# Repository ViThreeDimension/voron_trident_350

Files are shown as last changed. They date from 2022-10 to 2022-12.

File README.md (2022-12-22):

# My Voron Trident 350

This documentation is to know where to find replacement parts for the mods. 
When I will be at the software step, I will add klipper configs, make files. 

Built from this [Voron Trident R1 commit](https://github.com/VoronDesign/Voron-Trident/tree/VTr1)

[Voron 2.4 R0 - 300](https://github.com/ViThreeDimension/voron2.4) big brother

## Mods
- [Carbon Pin Mod](/mods/own%20mods/Trident%20Carbon%20Pin%20Mod/) (slightly lower holes diameter) based on [hartk pin mod](https://github.com/VoronDesign/VoronUsers/tree/master/printer_mods/hartk1213/Voron2.4_Trident_Pins_Mod) - [(fork)](https://github.com/ViThreeDimension/VoronUsers/tree/timelocked-mods/Trident/printer_mods/hartk1213/Voron2.4_Trident_Pins_Mod)
- [Fish3DP's front idlers "Tackle Box"](/mods/fishTackleBox/Fish%20Tackle%20Box%20other_front_idler.md)
- Umbelical
- Can Toolhead SHT-36
  - [Can Mount](/mods/STH-36_sherpa_mini_mounting_plate_overmold_strain.stl) from [KayorMaker Can Mount Repo](https://github.com/KayosMaker/CANboard_Mounts)
  - [CanBus Documentation](documentation_subpages/CAN%20configuration.md)
- [Toolhead smol mantis](/mods/smol_mantis/) from [FoonieTunes repo](https://github.com/sporkus/smol_mantis)
  - [Sherpa mini from annex](https://github.com/Annex-Engineering/Sherpa_Mini-Extruder)
  - [Mini Sherpa Angled Front Brace from Mandryd](https://github.com/Annex-Engineering/Annex-Engineering_User_Mods/tree/main/Extruders/Sherpa_Mini/Extruder_Mods/Long-housing_front_angled_front_brace)
  - Can Bus SHT-36 - [Documentation](https://mellow.klipper.cn/#/board/fly_sht36_42/)
- [KlickyNG](https://github.com/ViThreeDimension/Klicky-Probe/tree/timelocked-mods/Trident)
- [Sexbolt for Trident with kinematic bed](/mods/sexbolt%20trident%20for%20kinematic%20bed/) based on [sexbolt by hartk](https://github.com/hartk1213/MISC/tree/main/Voron%20Mods/Voron%202/2.4/Voron2.4_SexBolt_ZEndstop)
- Panel locker [by V6C1](https://github.com/v6cl/My-Voron2.4-Customs/tree/main/Panel_Locker)
- V2.2 doors modified for 5mm acrylic and 8mm foam: [here](mods/front%20panel%20handle)
- Gantry Backers [by whoppingpochard](https://github.com/ViThreeDimension/VoronUsers/tree/timelocked-mods/Trident/printer_mods/whoppingpochard/extrusion_backers)
- Trident kinematic_bed [by whoppingpochard](https://github.com/tanaes/whopping_Voron_mods/tree/main/kinematic_bed)
- [Nevermore](https://github.com/nevermore3d/Nevermore_Micro) and Nevermore Extension [by Outrider305](https://github.com/Outrider305/Nevermore_Spacer_Mount) - ([cache](https://github.com/ViThreeDimension/Nevermore_Spacer_Mount))
- [Decontaminator Bucket and brush](https://github.com/LoganFraser/VoronMods/blob/main/DecontaminatorTrident/)
- 
## Electronics
- 24v alimentation & 48v for A-B Motors
- SHT36 v1 for Toolhead - [Documentation](https://mellow.klipper.cn/#/board/fly_sht36_42/)
- Octopus Pro 446 main board 
  - [Official Documentation](https://github.com/bigtreetech/BIGTREETECH-OCTOPUS-Pro/) - [(cached)](documentation_subpages/BTT_Octopus_pro_EN.pdf)
  - [Klipper Installation (VoronDocs)](https://docs.vorondesign.com/build/software/octopus_klipper.html)
  - [My doc](documentation_subpages/BTT_Octopus_pro_vince.md)
- 110V bed heater

# Todo
- ADXL: Add Front keystone skirt

# Wishlist to sort
- [gcode buttons](https://github.com/VoronDesign/VoronUsers/tree/master/legacy_printers/printer_mods/meteyou/gcode_buttons)

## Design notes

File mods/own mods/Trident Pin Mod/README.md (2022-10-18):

Pin mod for the Voron Trident based on Hartk V2 work.

Need to print all gantry parts that has Idlers
- AB drive frames
- XY Joints
- Front Tensioners

Files

BOM
[A-B] 
threaded(or not) @  30mm (x2)
smooth   @  28mm (x2)

[X-Y Joints]
smooth   @  40mm (x4)

[X-Y Idlers]
smooth   @  43mm (x2)

Smooth pins

https://www.aliexpress.com/item/1739093502.html

threaded pins

https://www.ebay.com/itm/%CF%865mm-%CF%8612mm-Female-Thread-Cylindrical-Pin-Dowel-Pins-A2-304-Stainless-Steel/184373551069

Misumi Part Numbers
Part NO. 	Qty
SFRT5-30-M3 	2
SFR5-43 	2
SFR5-40 	4
SFR5-28 	2

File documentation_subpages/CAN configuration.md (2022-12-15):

# CAN Documentation

- [TeamFDM - how to use can toolhead boards connected directly to octopus pro](https://www.teamfdm.com/forums/topic/672-how-to-use-can-toolhead-boards-connected-directly-to-octopus-octopus-pro-on-canboot/)
- [Octopus Pro Documentation](https://github.com/bigtreetech/BIGTREETECH-OCTOPUS-Pro/) - [(cached pdf)](BTT_Octopus_pro_EN.pdf)
- [Mellow SHT36 CanBus Toolhead](https://mellow.klipper.cn/#/advanced/canboot)
  - UTOC device -> Bus 001 Device 003: ID 1d50:606f OpenMoko, Inc. 
- [Octopus and SB2040](https://github.com/akhamar/voron_canbus_octopus_sb2040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)
- [Maz0r Canbus for Klipper](https://maz0r.github.io/klipper_canbus/)
- EddieTheEngineer Videos
  - [Klipper Mainsail Can setup guide](https://www.youtube.com/watch?v=XkcxSQhRR3I)
  - [BTT EBB V1.0 CAN Setup Guide](https://www.youtube.com/watch?v=_FELCN8CbWA)
  - [Flash your Huvud over Canbus!](https://www.youtube.com/watch?v=YrF99Sff9g8)
  - [Flash all your klipper MCUs with 1 script](https://www.youtube.com/watch?v=1P4UrJxChL8) 

# My CAN configuration
- Start with UTOC-3 from Mazor https://maz0r.github.io/klipper_canbus/controller/utoc1-3.html

## PI Setup

` sudo nano /etc/network/interfaces.d/can0 `

auto can0
iface can0 can static
 bitrate 500000
 up ifconfig $IFACE txqueuelen 256
 pre-up ip link set can0 type can bitrate 500000
 pre-up ip link set can0 txqueuelen 256

and press Ctrl+X to save.

you can now reboot the pi with ` sudo reboot `
## Test the network

Once the pi has rebooted you can run the ip -s link show can0 command to check your network status.

You should see a line like the below in the results. The key thing to note is that the network is UP for now.

iplink

- If not working test this 
https://mellow.klipper.cn/#/advanced/can_rpi

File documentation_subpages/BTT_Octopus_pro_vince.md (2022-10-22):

# Settings Up Octopus Pro via USB-Powered (from PI) and DFU Mode  
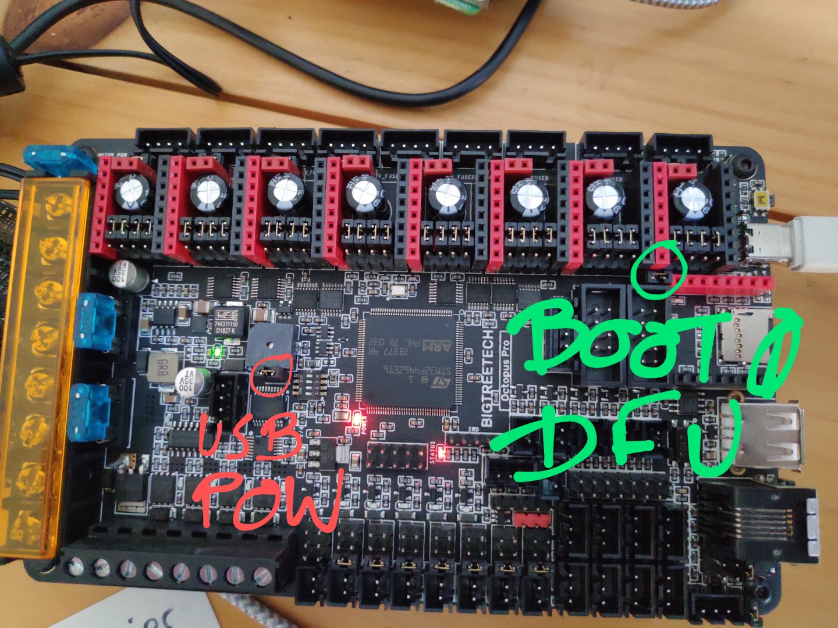
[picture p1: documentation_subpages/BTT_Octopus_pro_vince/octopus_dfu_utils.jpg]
Octopus pro in DFU-Utils/Boot0 mode


# Restore factory Octopus STM32F446 bootloader 
> Documentation by Dragonkitty ▞ replimat.eu - Drachenkätzchen#3832

My Octopus F446 wouldn't boot the Klipper CAN Firmware, so I hunted this down to a incompatible bootloader installed by BTT.
Surprisingly, their published bootloader on Github works. Here's how to flash it using dfu-util after putting the
board into DFU boot mode:

```
# Downloads the firmware file in Intel HEX format
wget https://raw.githubusercontent.com/bigtreetech/BIGTREETECH-OCTOPUS-V1.0/master/Firmware/DFU%20Update%20bootloader/bootloader/OctoPus-F446-bootloader-32KB.hex

# Converts the hex firmware to a bin
objcopy --input-target=ihex --output-target=binary OctoPus-F446-bootloader-32KB.hex bootloader.bin

# Optional: Backup the old bootloader
sudo dfu-util -d ,0483:df11 -R -a 0 -s 0x8000000:32768 -U old-bootloader.bin

# Install the new bootloader
sudo dfu-util -d ,0483:df11 -R -a 0 -s 0x8000000:leave -D bootloader.bin
```

Reset bootloader per @Dragonkitty ▞ replimat.eu  pin in CAN Bus stop  if required

# Configure Octopus in USB-Bridge Can bus
> Documentation by Maz | v2.☕ - maz#1337

- Configure [like normal Octopus firmware](https://docs.vorondesign.com/build/software/octopus_klipper.html) except change two the comms port & the can pins (screenshot for F446)
```
cd ~/klipper
make menuconfig
```
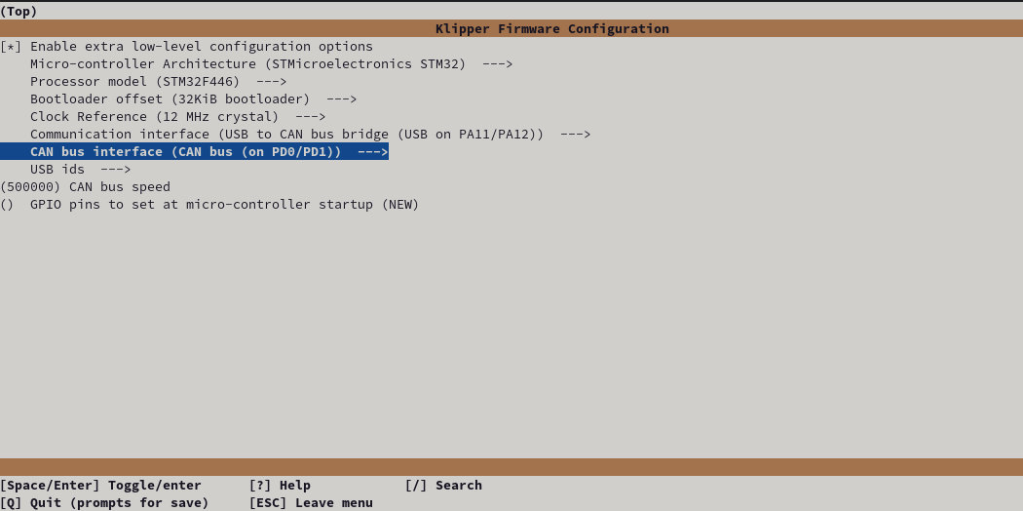
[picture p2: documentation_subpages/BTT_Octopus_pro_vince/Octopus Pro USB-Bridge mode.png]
outlined wiring


- setup CAN0 network 
```
sudo nano /etc/network/interfaces.d/can0
allow-hotplug can0
iface can0 can static
   bitrate 500000
   up ifconfig $IFACE txqueuelen 256
   pre-up ip link set can0 type can bitrate 500000
   pre-up ip link set can0 txqueueln 256
```

- continue setup of upstream devices which will be connected via a RJ11/12 breakout on the octopus

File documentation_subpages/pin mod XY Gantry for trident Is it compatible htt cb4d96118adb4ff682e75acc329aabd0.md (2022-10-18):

# pin mod XY Gantry for trident? Is it compatible? https://github.com/hartk1213/MISC/tree/main/Voron Mods/Voron 2/2.4/Voron2.4_Pins_Mod

- Need to tweak ab motors holder for this too

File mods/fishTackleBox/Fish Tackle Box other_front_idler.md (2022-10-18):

# Fish3DP (discord Fish3DP#2205) Tackle Box front idlers

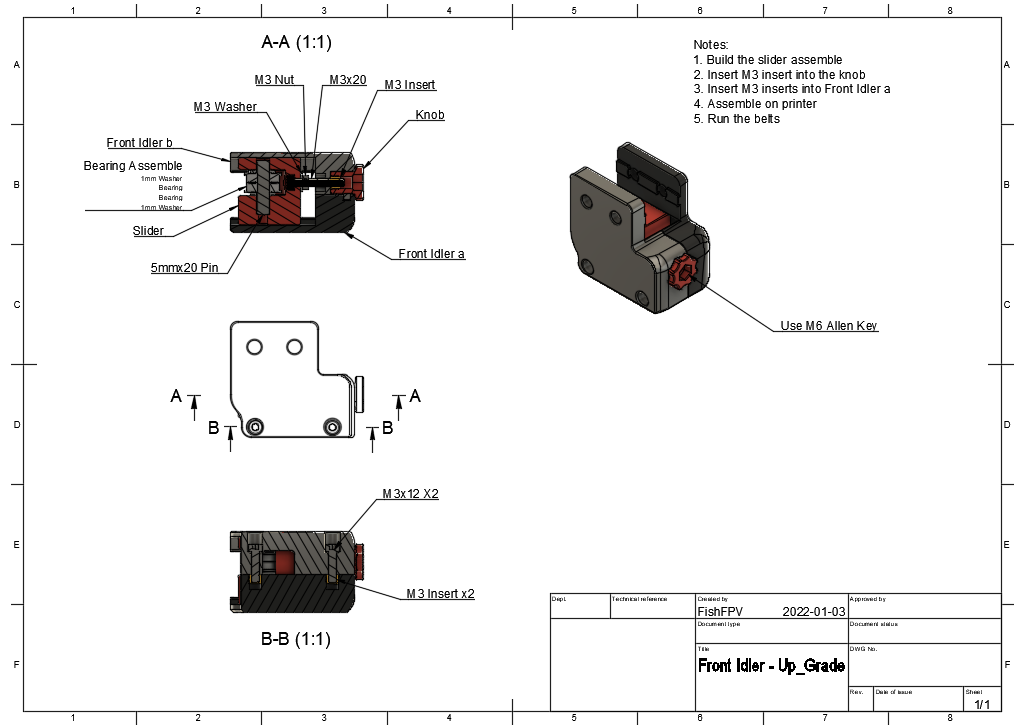
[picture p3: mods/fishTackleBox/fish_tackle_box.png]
fish tackle box.png


[Fishs_Tackle_Box_Tensions.zip](Fishs_Tackle_Box_Tensions.zip)

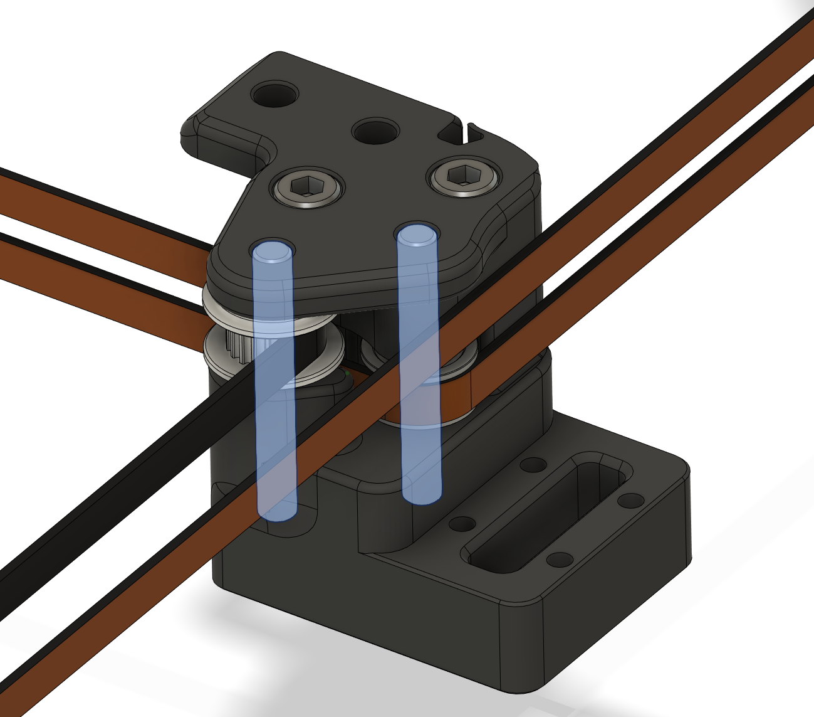
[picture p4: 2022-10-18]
mods/own mods/Trident Pin Mod/Images/XY_Right_Joint.png

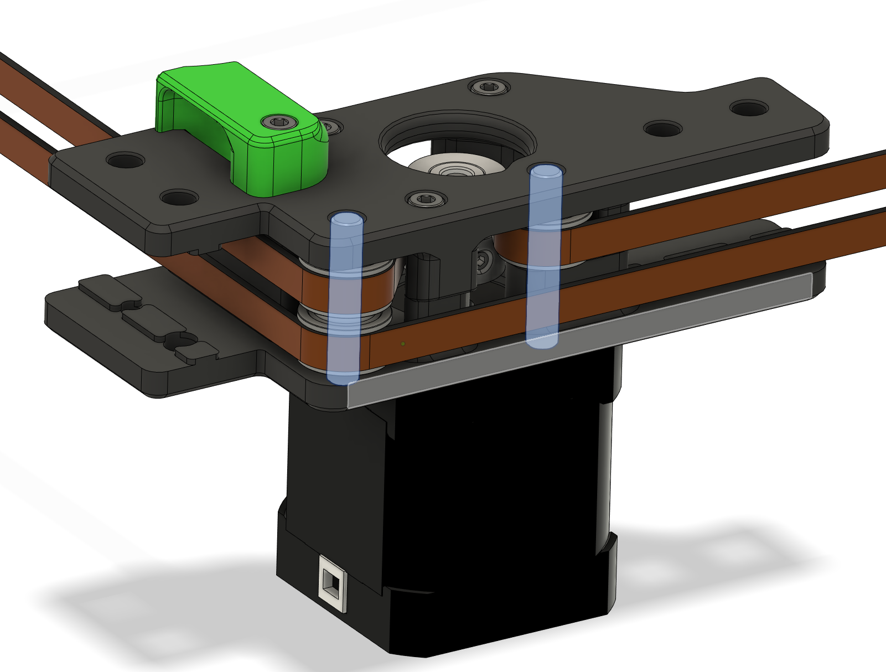
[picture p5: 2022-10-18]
mods/own mods/Trident Pin Mod/Images/A_Motor_Plate.png

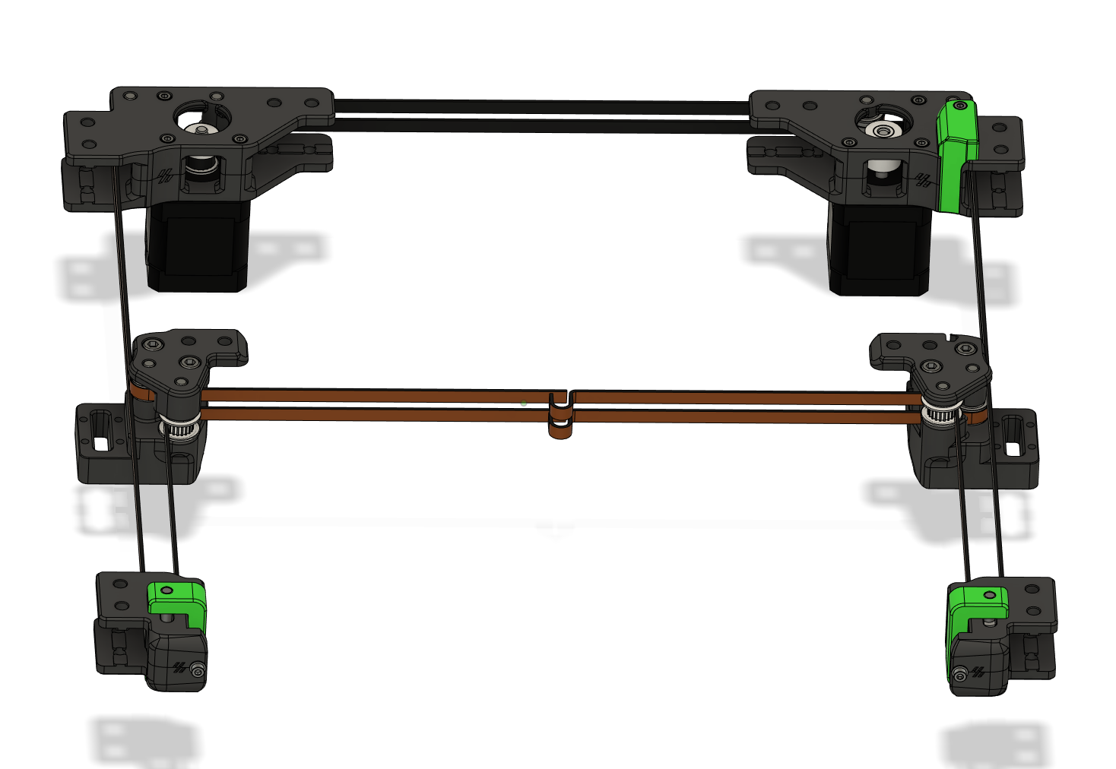
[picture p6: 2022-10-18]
mods/own mods/Trident Pin Mod/Images/Gantry.png

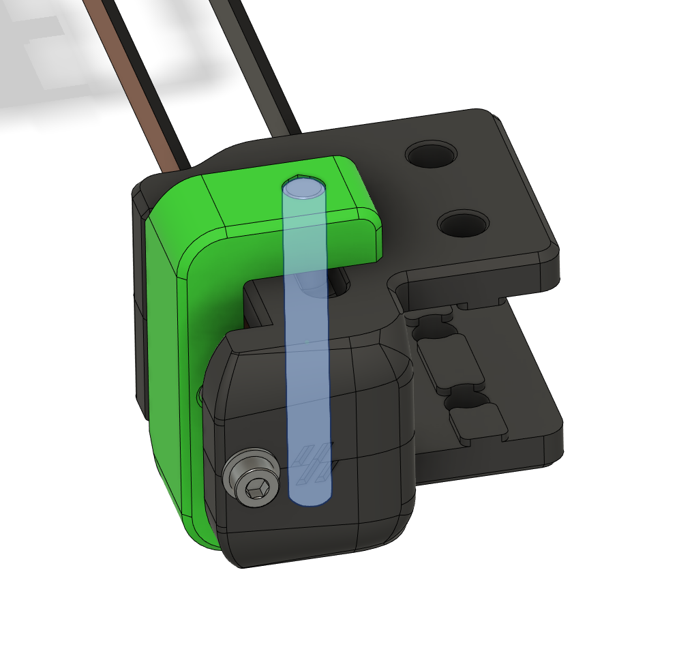
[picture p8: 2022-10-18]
mods/own mods/Trident Pin Mod/Images/Right_Idler.png

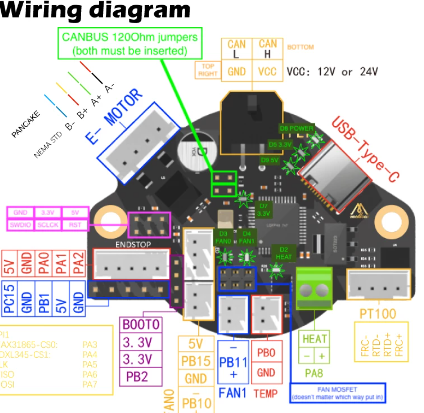
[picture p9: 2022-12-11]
documentation_subpages/sht36diag.png

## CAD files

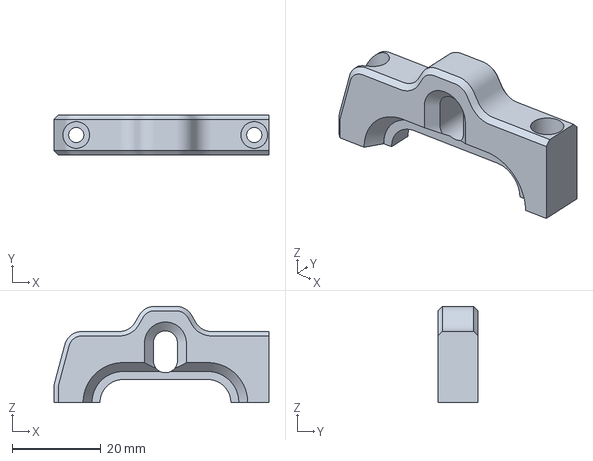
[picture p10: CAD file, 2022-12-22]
mods/front panel handle/handle_sandwich.3mf
48.3 x 9.00 x 21.6 mm

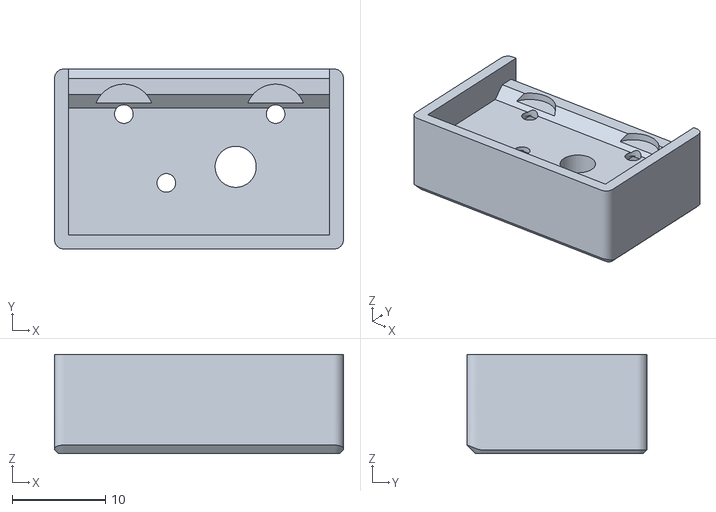
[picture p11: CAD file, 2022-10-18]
mods/klickyNG/KlickyNG_cap_magnet helper.stl
30.9 x 19.3 x 10.6

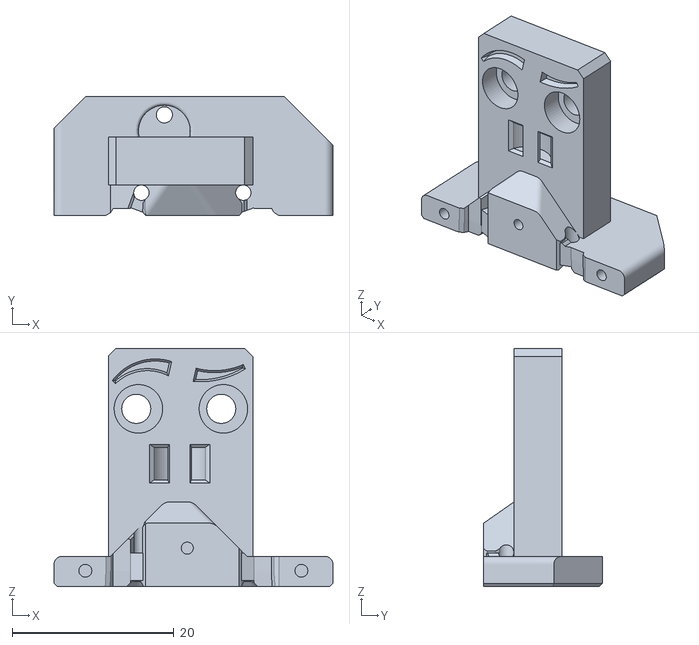
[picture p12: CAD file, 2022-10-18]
mods/klickyNG/STL/KlickyNG_ABSB_mount_base.stl
34.5 x 14.7 x 29.4

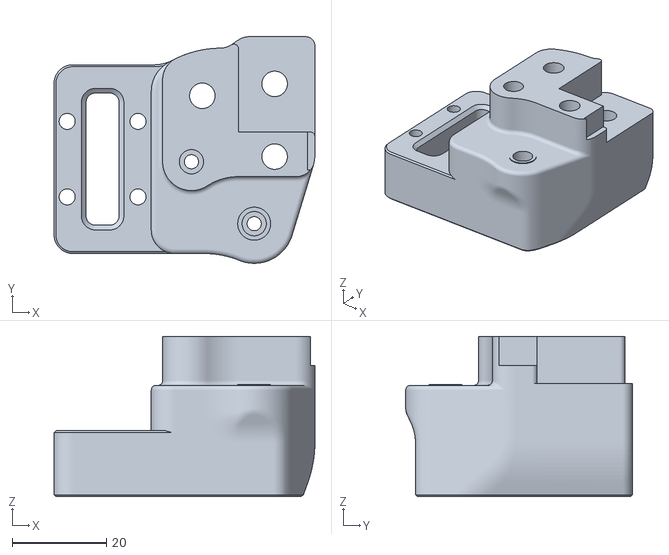
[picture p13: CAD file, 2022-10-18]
mods/own mods/Trident Carbon Pin Mod/xy_joint_left_lower_MGN12_pinned.stl
55.3 x 48.0 x 34.0

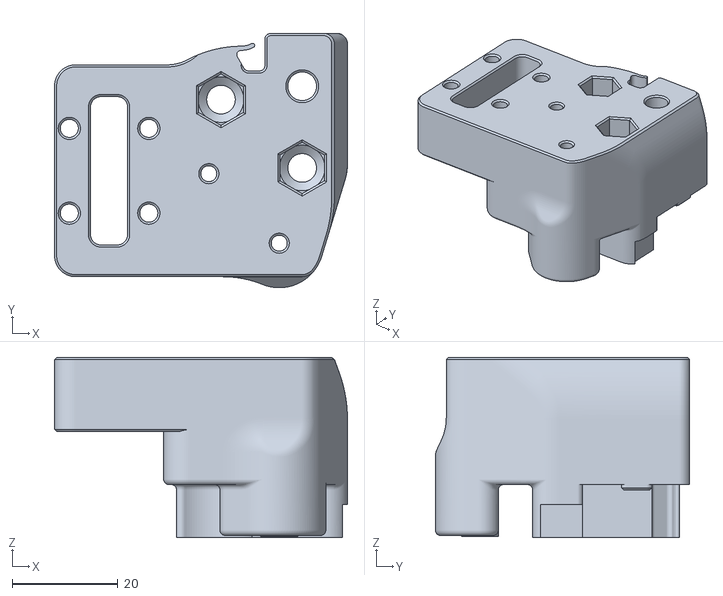
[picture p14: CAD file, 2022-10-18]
mods/own mods/Trident Pin Mod/STLs/xy_joint_right_lower_MGN12_pinned.stl
55.3 x 48.0 x 34.0

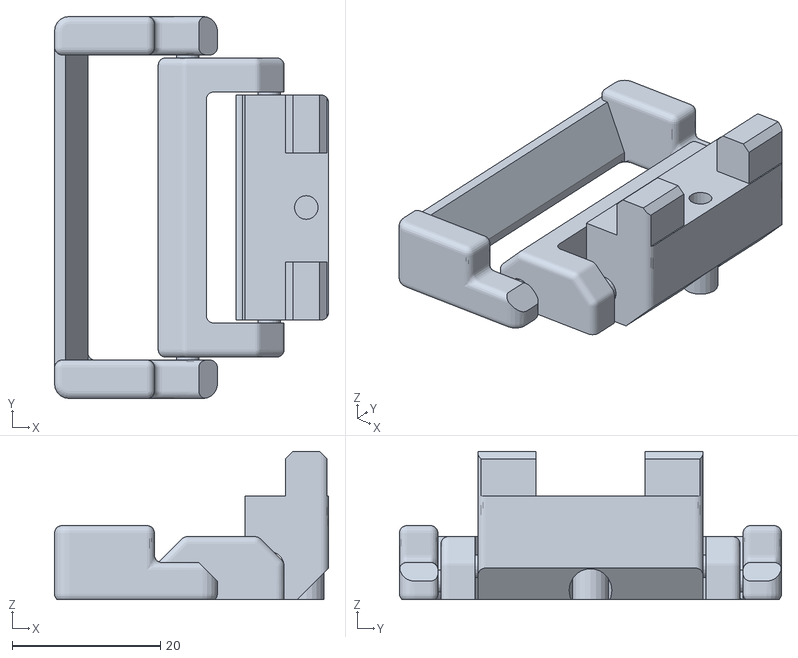
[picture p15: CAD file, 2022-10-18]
mods/Panel_Locker/Locker_5mm.stl
37.0 x 51.6 x 20.0

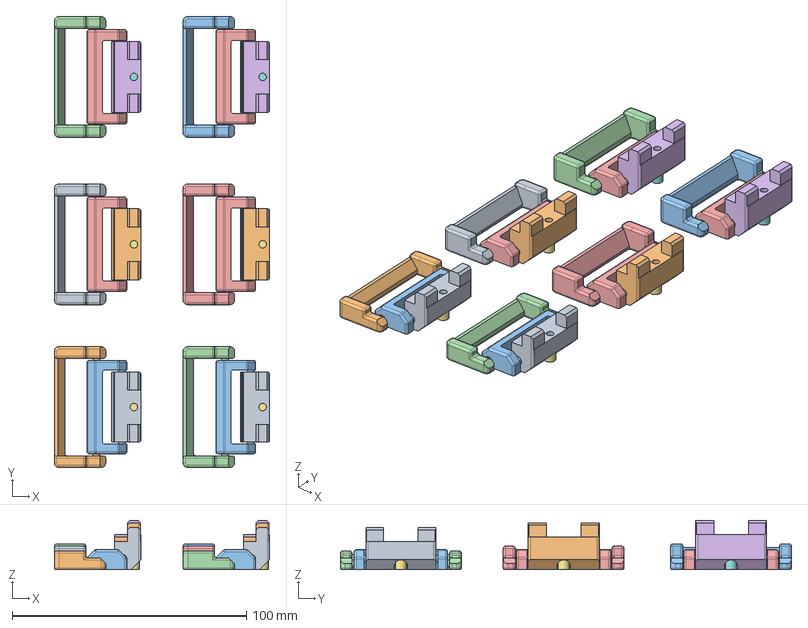
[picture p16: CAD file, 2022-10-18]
mods/Panel_Locker/step/PanelLocker.stp
92.0 x 192.6 x 21.0 mm

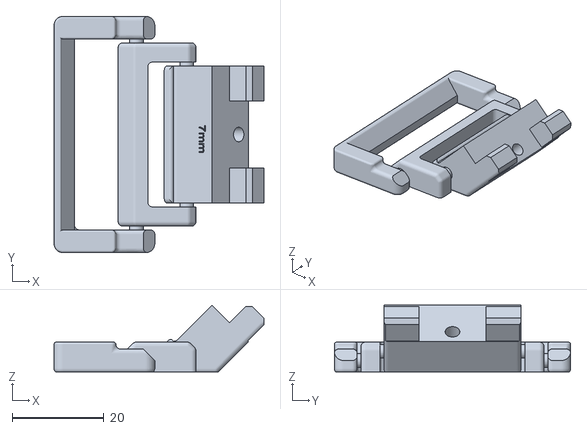
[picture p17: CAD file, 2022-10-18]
mods/Panel_Locker/Thin Locker/Thin_Locker_7mm.stl
45.8 x 51.6 x 14.6

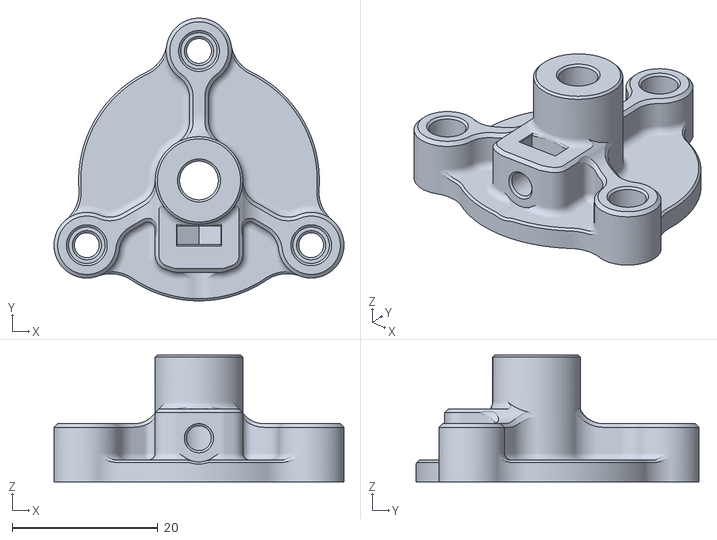
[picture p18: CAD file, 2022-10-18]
mods/Sherpa_Mini-Extruder-master/Assembly_Tools/Shaft_Grinding_Tool/top.stl
39.7 x 38.8 x 17.4

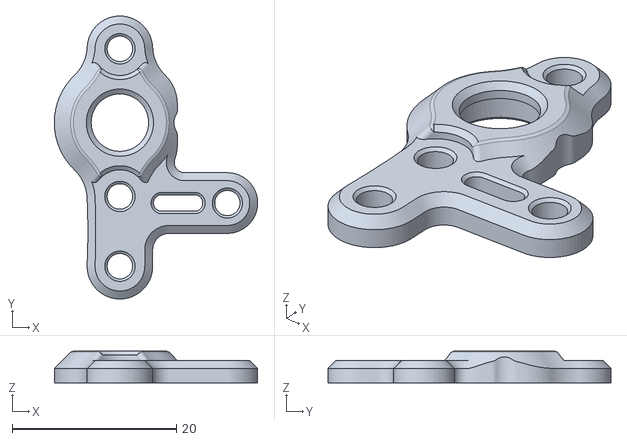
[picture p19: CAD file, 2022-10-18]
mods/Sherpa_Mini-Extruder-master/STLs/experimental_SLS+MJF_STLs/optional_parts/sls_[a]_housing_front_k_x1_rev1.STL
24.8 x 34.5 x 3.90

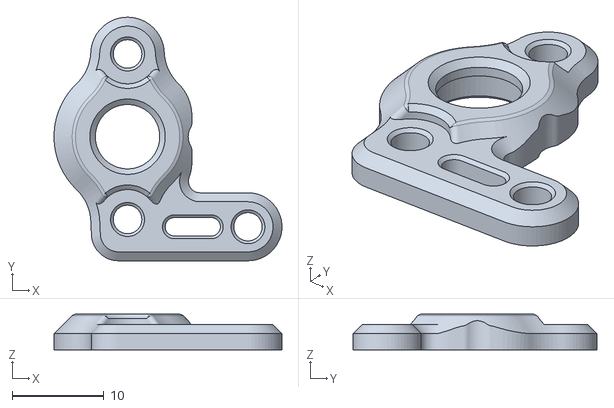
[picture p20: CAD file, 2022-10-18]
mods/Sherpa_Mini-Extruder-master/STLs/experimental_SLS+MJF_STLs/sls_[a]_housing_front_x1_rev1.STL
24.8 x 26.5 x 3.90

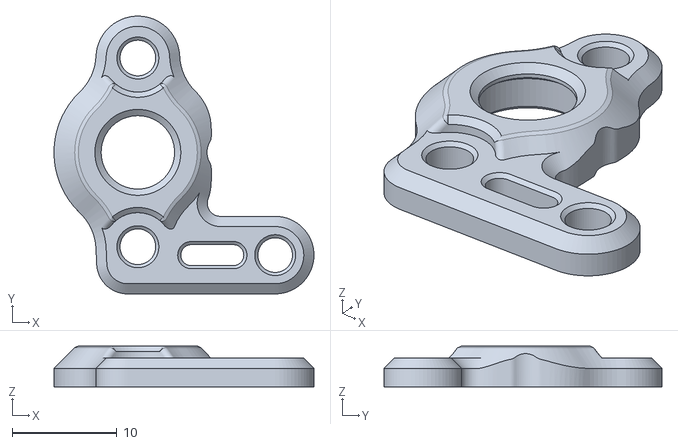
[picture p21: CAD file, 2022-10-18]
mods/Sherpa_Mini-Extruder-master/STLs/FDM_STLs/[a]_housing_front_x1_rev5.STL
24.8 x 26.5 x 3.90

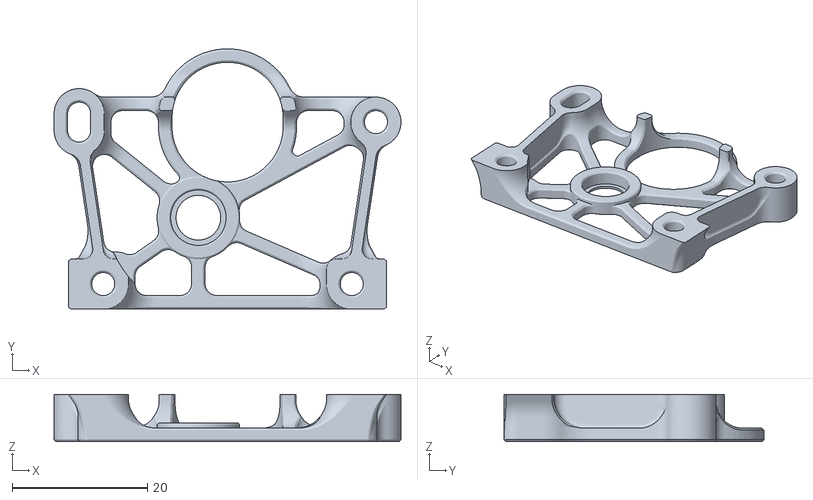
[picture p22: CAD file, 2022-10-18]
mods/Sherpa_Mini-Extruder-master/STLs/FDM_STLs/bondtech_inserts/housing_rear_bt_x1_rev1.STL
51.2 x 38.4 x 7.00

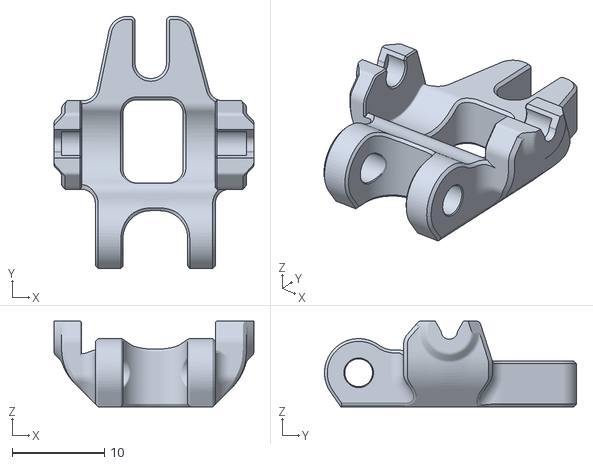
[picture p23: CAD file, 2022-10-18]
mods/Sherpa_Mini-Extruder-master/STLs/FDM_STLs/optional_parts/[a]_idler_arm_short_x1_rev5.STL
21.6 x 27.3 x 9.30

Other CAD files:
mods/STH-36_sherpa_mini_mounting_plate_overmold_strain.stl
mods/front panel handle/Front Panel - Handle Frame.3mf
mods/klickyNG/KlickyNG_Probe_Dock.stl
mods/klickyNG/STL/2mm_extender.stl
mods/Panel_Locker/Locker_3mm.stl
mods/Panel_Locker/Locker_6mm.stl
mods/Panel_Locker/Thin Locker/Thin_Locker_3.5mm.stl
mods/Panel_Locker/Thin Locker/Thin_Locker_3mm.stl
mods/Panel_Locker/Thin Locker/Thin_Locker_4.5mm.stl
mods/Panel_Locker/Thin Locker/Thin_Locker_4mm.stl
mods/Panel_Locker/Thin Locker/Thin_Locker_5.5mm.stl
mods/Panel_Locker/Thin Locker/Thin_Locker_5mm.stl
mods/Panel_Locker/Thin Locker/Thin_Locker_6.5mm.stl
mods/Panel_Locker/Thin Locker/Thin_Locker_6mm.stl
mods/Panel_Locker/Thin Locker/Thin_Locker_7.5mm.stl
mods/Panel_Locker/Thin_Locker_3mm.stl
mods/Panel_Locker/Thin_Locker_6mm.stl
mods/Panel_Locker/step/Thin_PanelLocker.stp
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

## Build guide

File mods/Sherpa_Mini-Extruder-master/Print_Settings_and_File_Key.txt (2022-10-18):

Primary Color: nothing at start of file name
Accent Color: [a]_ at start of file name
Quantity Required: _x# near end of file name
File Revision: _Rev# at end of file name

Nozzle Size: 0.4 Recommended, 0.6mm or 0.5mm Optional
Recommended FDM Materials: ASA, Polymaker, FilamentOne or 3DXTech Recommended
Alternate Approved FDM Materials: ABS, ABS+, 3DXtech or Atomic Filaments Recommended

Below Settings are for a 0.4mm Nozzle
Layer Height: 0.1mm or 0.2mm
Extrusion Width: Forced 0.4mm
Infill Percentage: 40% minimum (at 0.6mm Width)
Infill Type: Grid, Gyroid, Honeycomb, Triangle or Cubic
Wall Count: 3 minimum (at 0.4mm Width)
Solid Top/Bottom Layers: 5 minimum (at 0.2mm Height)

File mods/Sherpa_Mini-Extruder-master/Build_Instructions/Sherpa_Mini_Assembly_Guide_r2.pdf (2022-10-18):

# Sherpa Mini Assembly Guide

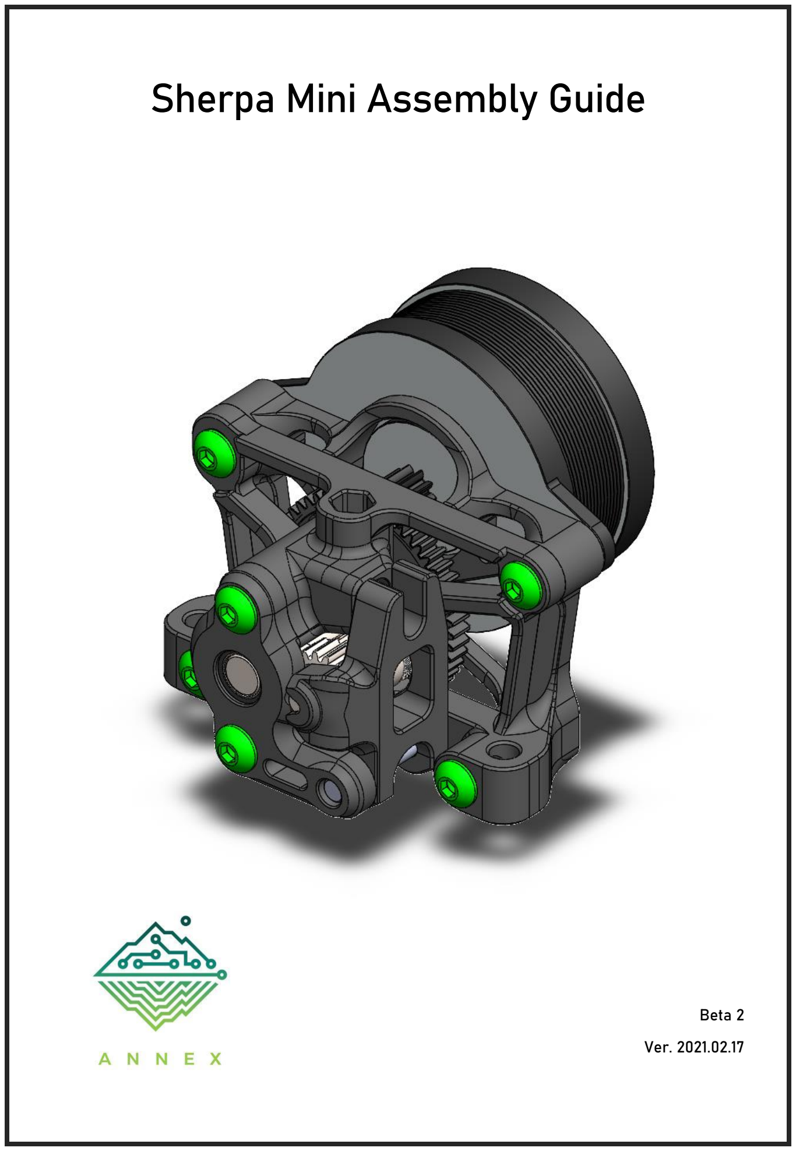
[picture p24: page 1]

Beta 2

Ver. 2021.02.17

# Parts List

Here are all the parts you will need to build your Sherpa Mini

- 1 set printed parts
- 1 set Bondtech BMG Dual Drive gearset (5mm)
- 1 set BMG idler tensioner assembly (screw + spring)
- 5x heat set insert
- 5x M3x4x5mm (IDxLxW) OR
- 4x M3x4x5 + 1x M3x6x5mm
- 2x MR85 bearing (2RS preferred)
- 2x 20mm shaft
- The idler pivot shaft can be longer but will poke out the back
- 1x 5x7x0.5mm (IDxODxL) shim washer (a printed one will do in a pinch)
- 2x M3x16 BHCS
- 2x M3x8 BHCS
- 2x M3x14 BHCS
- You can substitute M3x16 BHCS
- 1x NEMA14 round body pancake stepper (LDO 36STH17-AHG)

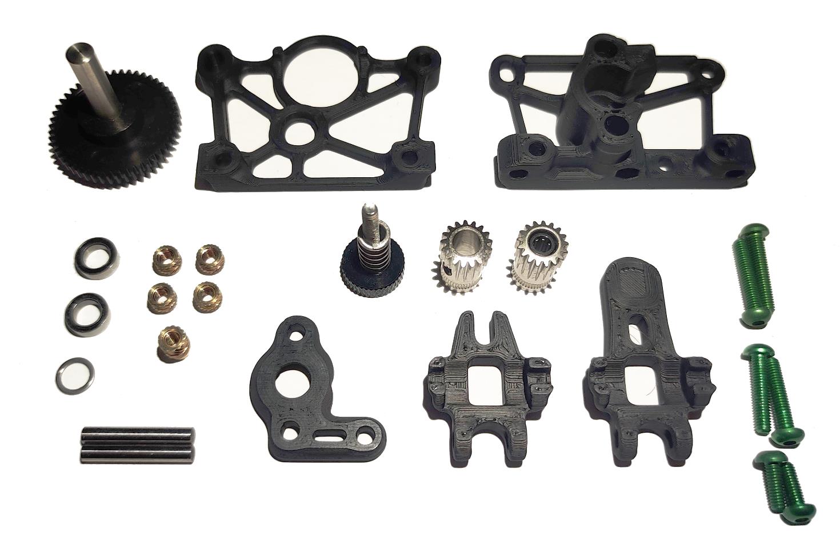
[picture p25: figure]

# Prep Work

## 1. Install bearings and heat set inserts

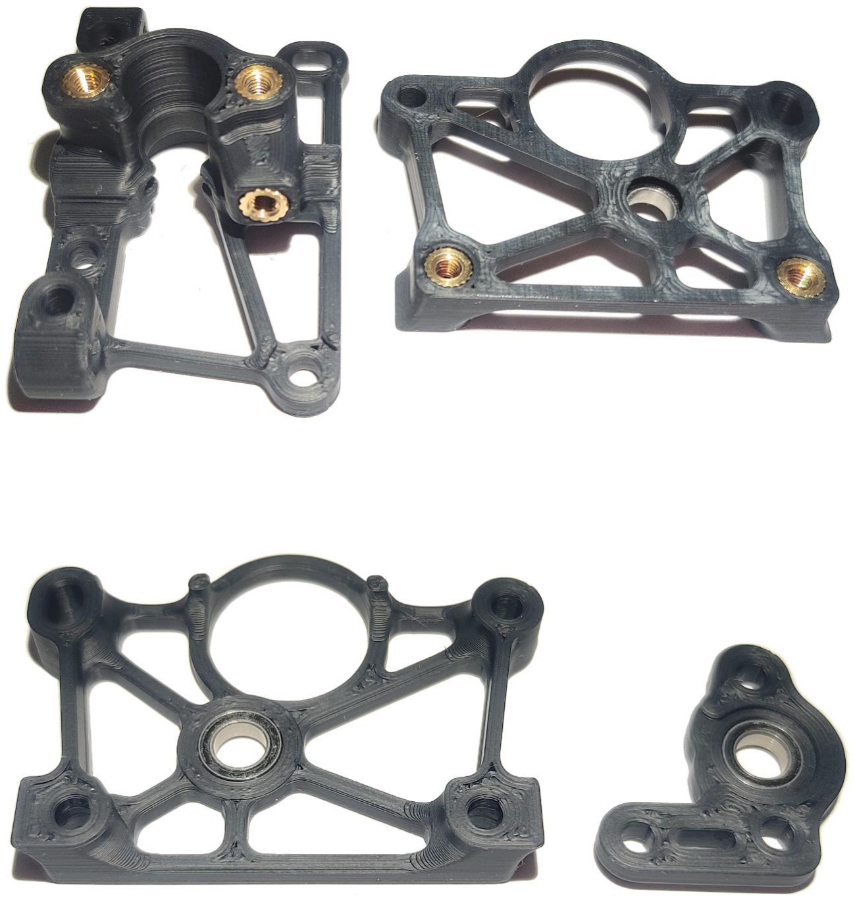
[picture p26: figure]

## 2. Clean up the filament path with a 2mm drill bit

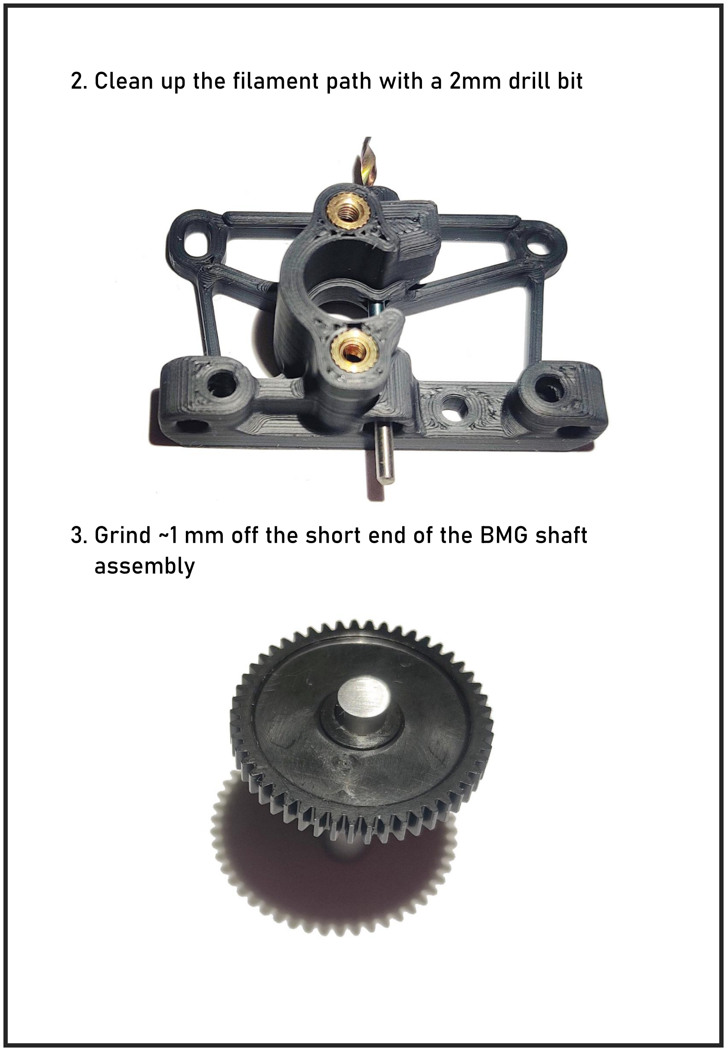
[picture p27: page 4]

## 3. Grind ~1 mm off the short end of the BMG shaft assembly

## 4. Build the idler arm assembly

- Clean the pivot shaft holes with a 3mm drill bit if necessary
- The idler shaft is a snap fit
- Grease the idler needle bearings prior to assembly
- Make sure the idler gear spins freely

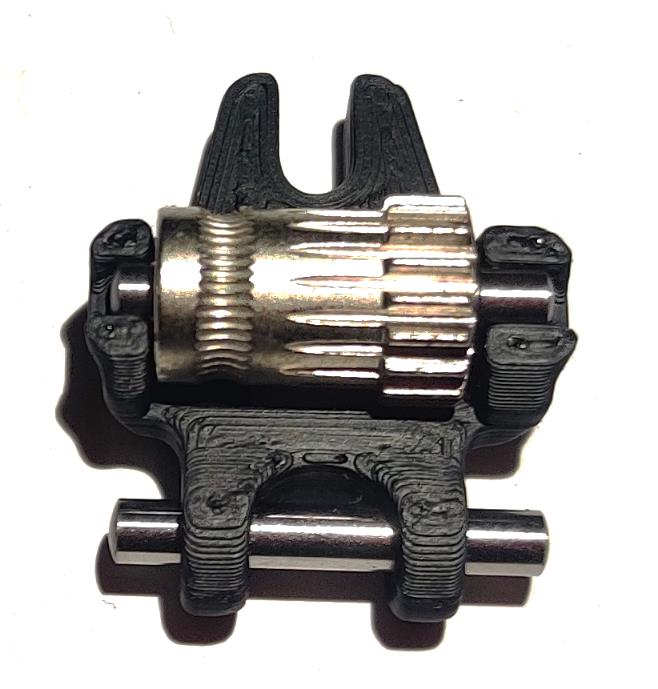
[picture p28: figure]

# Assembly Steps

## 1. Insert the BMG shaft assembly into the rear housing

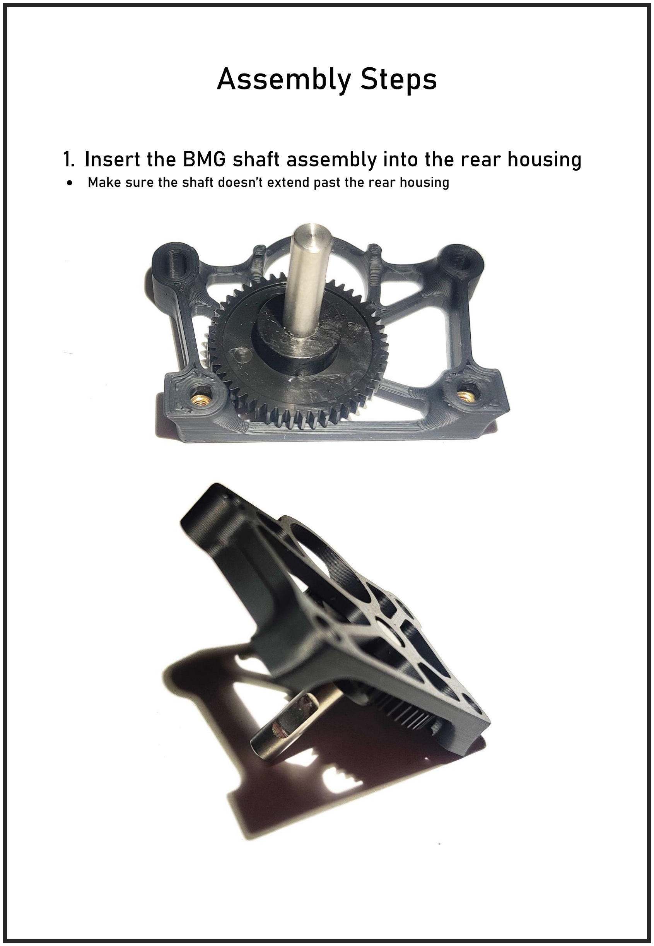
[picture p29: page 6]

- Make sure the shaft doesn’t extend past the rear housing

## 2. Install the core housing and the lower two M3x16 screws

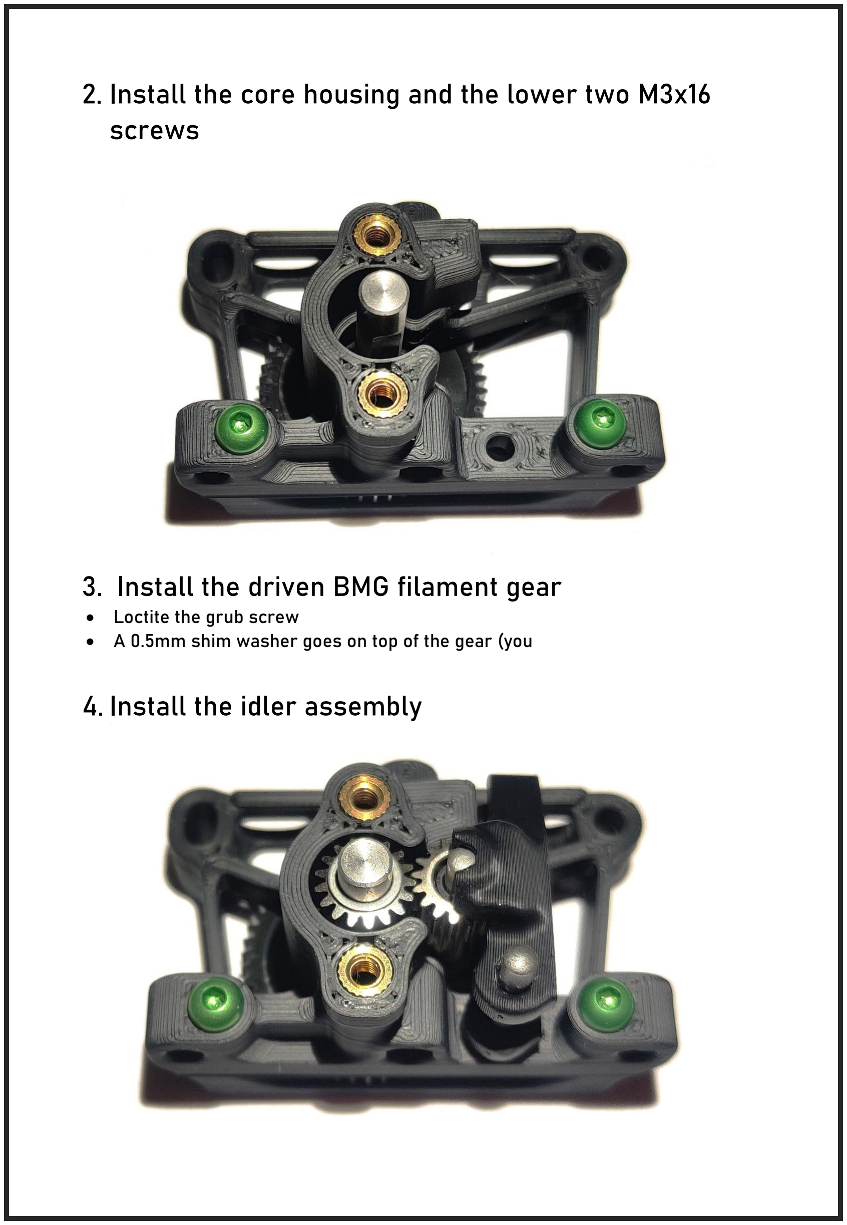
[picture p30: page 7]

## 3. Install the driven BMG filament gear

- Loctite the grub screw
- A 0.5mm shim washer goes on top of the gear (you

## 4. Install the idler assembly

## 5. Install the front housing

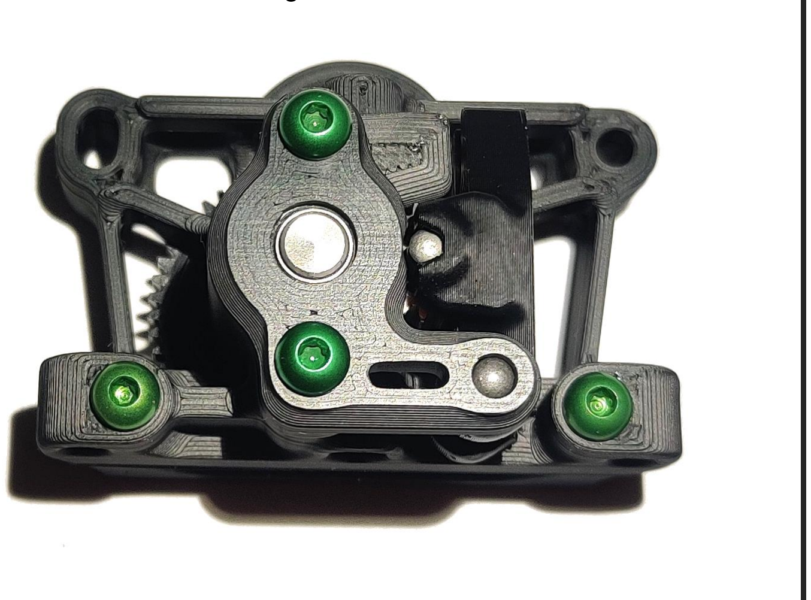
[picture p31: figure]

## 6. Make sure the main gear turns freely and no part of the idler arm bottoms out on the core

## 7. Mount the motor and adjust gear meshing

- There should only be a tiny bit of backlash when the gears are meshed properly

## 8. Install the tensioner spring and thumbscrew

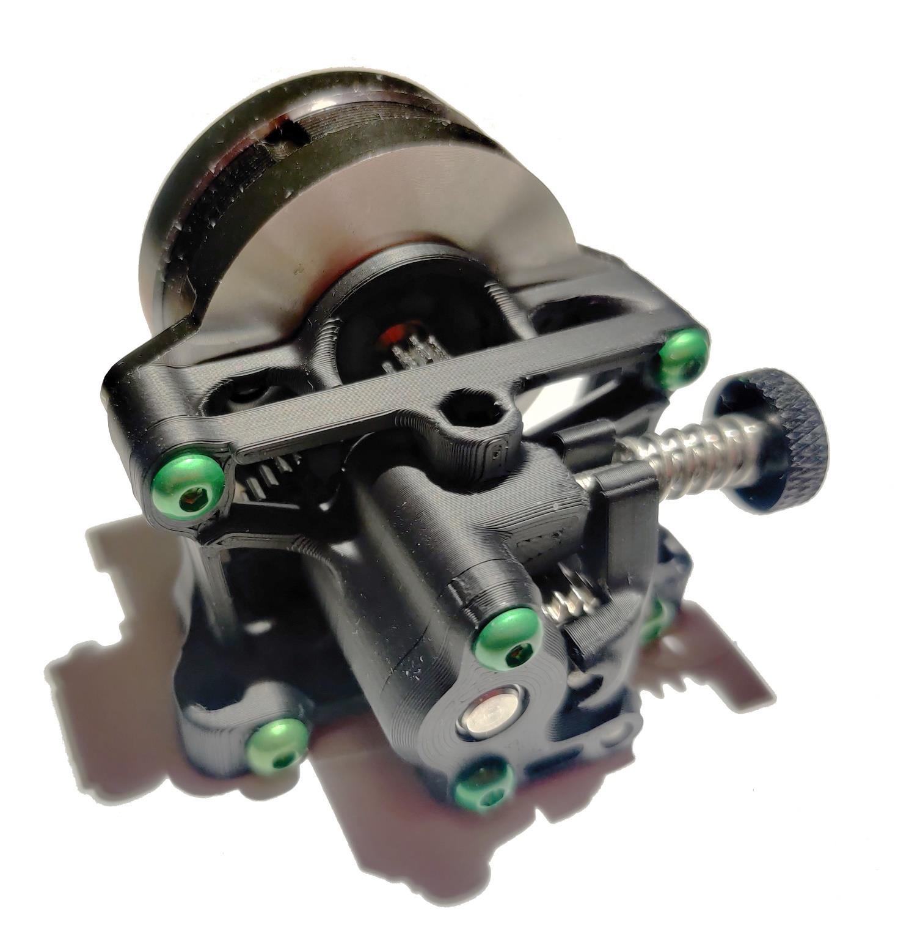
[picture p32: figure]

## 9. Done! For further help with assembly and configuration please see the Annex Engineering GitHub page or join our Discord server

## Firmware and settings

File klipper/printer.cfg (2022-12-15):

# This file contains common pin mappings for the BigTreeTech Octopus V1.
# To use this config, the firmware should be compiled for the STM32F446 with a "32KiB bootloader"
# Enable "extra low-level configuration options" and select the "12MHz crystal" as clock reference

# after running "make", copy the generated "klipper/out/klipper.bin" file to a
# file named "firmware.bin" on an SD card and then restart the OctoPus with that SD card.

# See docs/Config_Reference.md for a description of parameters.

## Voron Design Trident 250/300/350mm BigTreeTech OctoPus V1 TMC2209 UART config
# scp -r .\klipper\* pi@192.168.x.y:~/klipper_config

[include mainsail.cfg]
[include klicky/klicky-probe.cfg]


## *** THINGS TO CHANGE/CHECK: ***
## MCU paths                            [mcu] section
## Thermistor types                     [extruder] and [heater_bed] sections - See https://www.klipper3d.org/Config_Reference.html#common-thermistors for common thermistor types
## Leadscrew Rotation Distance          [stepper_z], [stepper_z1], [stepper_z2]
## Z Endstop Switch location            [safe_z_home] section
## Z Endstop Switch  offset for Z0      [stepper_z] section
## PID tune                             [extruder] and [heater_bed] sections
## Probe pin                            [probe] section
## Fine tune E steps                    [extruder] section
      

[mcu] # Octopus main board
serial: /dev/serial/by-id/usb-Klipper_stm32f446xx_0D0043000250534E4E313120-if00
restart_method: command

[static_digital_output disable_max31865]
pins: !PF8

[printer]
kinematics: corexy
max_velocity: 300  
max_accel: 3000             #Max 4000
max_accel_to_decel: 3000
max_z_velocity: 15          #Max 15 for 12V TMC Drivers, can increase for 24V
max_z_accel: 350
square_corner_velocity: 10.0

#####################################################################
#   X/Y Stepper Settings
#####################################################################

##  B Stepper - Left
##  Connected to MOTOR_7
[stepper_x]
step_pin: PE6 
dir_pin: PA14
enable_pin: !PE0
rotation_distance: 40
microsteps: 32
full_steps_per_rotation:200  #set to 400 for 0.9 degree stepper
position_min: 0
position_endstop: 350
position_max: 350
homing_speed: 80   #Max 100
homing_retract_dist: 5
homing_positive_dir: true

##  Make sure to update below for your relevant driver (2208 or 2209)
[tmc2209 stepper_x]
uart_pin: PD3 # mot0 - PC4
### Below for 5160HV wasn't able to make them work
# [tmc5160 stepper_x]
#cs_pin: PD3 
#spi_bus: spi3 not tested with this
# spi_software_miso_pin: PA6
# spi_software_mosi_pin: PA7
# spi_software_sclk_pin: PA5
interpolate: False
run_current: 0.8
sense_resistor: 0.110
stealthchop_threshold: 0

##  A Stepper - Right
##  Connected to MOTOR_6
##  Endstop connected to DIAG_1
[stepper_y]
step_pin: PE2
dir_pin: PE3
enable_pin: !PD4
rotation_distance: 40
microsteps: 32
full_steps_per_rotation:200  #set to 400 for 0.9 degree stepper
endstop_pin: PG9
position_min: 0
position_endstop: 350
position_max: 350
homing_speed: 80  #Max 100
homing_retract_dist: 5
homing_positive_dir: true

##  Make sure to update below for your relevant driver (2208 or 2209)
[tmc2209 stepper_y]
uart_pin: PE1
#### Below for 5160HV wasn't able to make them work
# [tmc5160 stepper_y]
# cs_pin: PE1
# spi_software_miso_pin: PA6
# spi_software_mosi_pin: PA7
# spi_software_sclk_pin: PA5
interpolate: False
run_current: 0.8
sense_resistor: 0.110
stealthchop_threshold: 0
 
#####################################################################
#   Z Stepper Settings
#####################################################################

##  Z0 Stepper - Front Left
##  Connected to MOTOR_5
##  Endstop connected to DIAG_2
[stepper_z]
step_pin: PC13
dir_pin: !PF0
enable_pin: !PF1
# Rotation Distance for TR8x8 = 8, TR8x4 = 4, TR8x2 = 2
rotation_distance: 8    
microsteps: 32
endstop_pin: PG10
##  Z-position of nozzle (in mm) to z-endstop trigger point relative to print surface (Z0)
##  (+) value = endstop above Z0, (-) value = endstop below
##  Increasing position_endstop brings nozzle closer to the bed
##  After you run Z_ENDSTOP_CALIBRATE, position_endstop will be stored at the very end of your config
position_endstop: 2.25
## All builds use same Max Z
position_max: 230
position_min: -2.5
homing_speed: 6.0 # Leadscrews are slower than 2.4, 10 is a recommended max.
second_homing_speed: 3
homing_retract_dist: 3

##  Make sure to update below for your relevant driver (2208 or 2209)
[tmc2209 stepper_z]
uart_pin: PE4
interpolate: False
run_current: 0.6
sense_resistor: 0.110
stealthchop_threshold: 0

##  Z1 Stepper - Rear Center
##  Connected to MOTOR_4
[stepper_z1]
step_pin: PF9
dir_pin: !PF10
enable_pin: !PG2
# Rotation Distance for TR8x8 = 8, TR8x4 = 4, TR8x2 = 2
rotation_distance: 8  
microsteps: 32

##  Make sure to update below for your relevant driver (2208 or 2209)
[tmc2209 stepper_z1]
uart_pin: PF2
interpolate: False
run_current: 0.6
sense_resistor: 0.110
stealthchop_threshold: 0

##  Z2 Stepper - Front Right
##  Connected to MOTOR_3
[stepper_z2]
step_pin: PG4
dir_pin: !PC1
enable_pin: !PA0
# Rotation Distance for TR8x8 = 8, TR8x4 = 4, TR8x2 = 2
rotation_distance: 8  
microsteps: 32

##  Make sure to update below for your relevant driver (2208 or 2209)
[tmc2209 stepper_z2]
uart_pin: PC7
interpolate: False
run_current: 0.6
sense_resistor: 0.110
stealthchop_threshold: 0


#####################################################################
#   Bed Heater
#####################################################################

[heater_bed]
##  SSR Pin - HE1
##  Thermistor - TB
heater_pin: PA2
## Check what thermistor type you have. See https://www.klipper3d.org/Config_Reference.html#common-thermistors for common thermistor types.
## Use "Generic 3950" for Keenovo heaters
sensor_type: Generic 3950
sensor_pin: PF3
##  Adjust Max Power so your heater doesn't warp your bed. Rule of thumb is 0.4 watts / cm^2 .
max_power: 0.6
min_temp: 0
max_temp: 120
#control: pid
#pid_kp: 58.437
#pid_ki: 2.347
#pid_kd: 363.769

#####################################################################
#   Probe
#####################################################################

[probe]
##  Inductive Probe
##  This probe is not used for Z height, only Quad Gantry Leveling

# Select the probe port by type:
## For the PROBE port. Will not work with Diode. May need pull-up resistor from signal to 24V.
#pin: ~!PB7
## For the DIAG_7 port. NEEDS BAT85 DIODE! Change to !PG15 if probe is NO.
#pin: PG15
## For Octopus Pro Probe port; NPN and PNP proximity switch types can be set by jumper
#pin: ~!PC5

#--------------------------------------------------------------------
pin: ^sht36:PA1
x_offset: 0
y_offset: 25.0
z_offset: 0
speed: 10.0
samples: 1
samples_result: median
sample_retract_dist: 3.0
samples_tolerance: 0.006
samples_tolerance_retries: 3

#####################################################################
#   Homing and Gantry Adjustment Routines
#####################################################################

[idle_timeout]
timeout: 1800

# [safe_z_home] # handled by klicky
# ##  XY Location of the Z Endstop Switch
# ##  Update -10,-10 to the XY coordinates of your endstop pin 
# ##  (such as 157,305) after going through Z Endstop Pin
# ##  Location Definition step.
# home_xy_position:196,350
# speed:80
# z_hop:10

[z_tilt]
z_positions:
   -50, 18
   175, 398
   400, 18
points:
   30, 5
   175, 295
   320, 5

speed: 200
horizontal_move_z: 25
retries: 5
retry_tolerance: 0.0075

[bed_mesh]
speed: 300
horizontal_move_z: 10
mesh_min: 15,25
mesh_max: 335,325
fade_start: 0.7
fade_end: 10.0
probe_count: 7,7
algorithm: bicubic
mesh_pps: 2,2
relative_reference_index: 25

#####################################################################
#   Fan Control
#####################################################################
[controller_fan controller_fan]
##  Controller fan - FAN2
pin: PD12
kick_start_time: 0.5
heater: heater_bed

#[heater_fan exhaust_fan]
##  Exhaust fan - FAN3
#pin: PD13
#max_power: 1.0
#shutdown_speed: 0.0
#kick_start_time: 5.0
#heater: heater_bed
#heater_temp: 60
#fan_speed: 1.0


#####################################################################
#   TEMP Control
#####################################################################
[temperature_sensor b_motor]
sensor_type: PT1000
sensor_pin: PF4

[temperature_sensor frame]
sensor_type: PT1000
sensor_pin: PF5
#####################################################################
#   LED Control
#####################################################################

#[output_pin caselight]
# Chamber Lighting - HE2 Connector (Optional)
#pin: PB10
#pwm:true
#shutdown_value: 0
#value:1
#cycle_time: 0.01

########################################
# EXP1 / EXP2 (display) pins
########################################
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

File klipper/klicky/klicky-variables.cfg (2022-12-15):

# This macro was provided by discord user Garrettwp to whom i give my thanks for sharing it with me.
# I have tweaked it a lot.
# They are based on the great Annex magprobe dockable probe macros "#Originally developed by Mental,
# modified for better use on K-series printers by RyanG and Trails", kudos to them.
# That macro as since evolved into a klipper plugin that currently is pending inclusion in klipper,
# more information here, https://github.com/Annex-Engineering/Quickdraw_Probe/tree/main/Klipper_Macros
# User richardjm revised the macro variables and added some functions, thanks a lot
# by standing on the shoulders of giants, lets see if we can see further
#
# the current home for this version is https://github.com/jlas1/Klicky-Probe
# the 1000 values below is to give an error instead of doing something wrong, hopefully, this won't be used is a printer larger than 1 meter

[gcode_macro _User_Variables]
variable_verbose:             True    # Enable verbose output
variable_debug:              False    # Enable Debug output
variable_travel_speed:         200    # how fast all other travel moves will be performed when running these macros
variable_move_accel:          2000    # how fast should the toolhead accelerate when moving
variable_dock_speed:            80    # how fast should the toolhead move when docking the probe for the final movement
variable_release_speed:         75    # how fast should the toolhead move to release the hold of the magnets after docking
variable_z_drop_speed:          20    # how fast the z will lower when moving to the z location to clear the probe

variable_safe_z:         	    35    # Minimum Z for attach/dock and homing functions
# if true it will move the bed away from the nozzle when Z is not homed
variable_enable_z_hop:        True    # set this to false for beds that fall significantly under gravity (almost to Z max)

variable_max_bed_y:            350    # maximum Bed size avoids doing a probe_accuracy outside the bed
variable_max_bed_x:            350    # maximum Bed size avoids doing a probe_accuracy outside the bed

# if a separate Z endstop switch is in
# use, specify the coordinates of the switch here (Voron).
# Set to 0 to have the probe move to center of bed
variable_z_endstop_x:         198.8
variable_z_endstop_y:         350

#Check the printer specific documentation on klipper Dock/Undock configuration, these are dummy values
#dock location
variable_docklocation_x:      136.5    # X Dock position
variable_docklocation_y:      346.5    # Y Dock position
variable_docklocation_z:      -128    # Z dock position (-128 for a gantry/frame mount)

#The following variables are used if the dock is deployed and retracted via a servo motor
variable_enable_dock_servo:  False    # Set to true if your klicky dock is servo-controlled
variable_servo_name:        'NAME'    # The name of the dock servo defined in printer.cfg under [servo]
variable_servo_deploy:          10    # This EXAMPLE is the value used to deploy the servo fully
variable_servo_retract:         11    # This EXAMPLE is the value used to retract the servo fully (initial_angle in [servo] config)
variable_servo_delay:          250    # This is a delay to wait the servo to reach the requested position, be carefull with high values

#Dock move, final toolhead movement to release the probe on the dock
#it's a relative move
Variable_dockmove_x:             -80
Variable_dockmove_y:             0
Variable_dockmove_z:             0

#Attach move. final toolhead movement to attach the probe on the mount
#it's a relative move
Variable_attachmove_x:           0
Variable_attachmove_y:           50
Variable_attachmove_z:           0

#Umbilical to help untangle the umbilical in difficult situations
variable_umbilical:          False    # should we untangle the umbilical
variable_umbilical_x:           15    # X umbilical position
variable_umbilical_y:           15    # Y umbilical position

# location to park the toolhead
variable_park_toolhead:      False    # Enable toolhead parking
variable_parkposition_x:       350
variable_parkposition_y:       300
variable_parkposition_z:        30

variable_version:                1    # Helps users to update the necessary variables, do not update if the variables above are not updated

#Below this remark, you normally do not need to configure
#Attach move2
Variable_attachmove2_x:          0    # intermediate toolhead movement to attach
Variable_attachmove2_y:          0    # the probe on the dock
Variable_attachmove2_z:          0    # (can be negative)

variable_home_backoff_x:        10    # how many mm to move away from the X endstop after homing X
                                      # this is useful for the voron v0 to enable the toolhead to move out of the way to allow an unstricted Y homing
variable_home_backoff_y:        10    # how many mm to move away from the Y endstop after homing Y

variable_override_homing:       ''    # configures what axis to home first
                                      #  '' = default klicky behavior (tries to avoid the hitting the dock)
                                      # 'X' = forces X to home first
                                      # 'Y' = forces Y to home first
                                      
variable_dock_on_zhome:       False    # docks the probe on Z Homing if not necessary (avoids hitting the bed on some printers                                      

# Do not modify below
gcode:
    {% set Mx = printer['configfile'].config["stepper_x"]["position_max"]|float %}
    {% set My = printer['configfile'].config["stepper_y"]["position_max"]|float %}
    {% set Ox = printer['configfile'].config["probe"]["x_offset"]|float %}
    {% set Oy = printer['configfile'].config["probe"]["y_offset"]|float %}
    {% set Oz = printer['configfile'].config["probe"]["z_offset"]|float %}

    # If x, y coordinates are set for z endstop, assign them
    {% if z_endstop_x != 0 or z_endstop_y != 0 %}
        SET_GCODE_VARIABLE MACRO=_Probe_Variables VARIABLE=z_endstop_x VALUE={ z_endstop_x }
        SET_GCODE_VARIABLE MACRO=_Probe_Variables VARIABLE=z_endstop_y VALUE={ z_endstop_y }

    # if no x, y coordinates for z endstop, assume probe is endstop and move toolhead to center of bed
    {% else %}
        SET_GCODE_VARIABLE MACRO=_Probe_Variables VARIABLE=z_endstop_x VALUE={ (Mx * 0.5) - Ox }
        SET_GCODE_VARIABLE MACRO=_Probe_Variables VARIABLE=z_endstop_y VALUE={ (My * 0.5) - Oy }
    {% endif %}

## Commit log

2022-10-18 First throw of documentation
    [2mm_extender.stl, DIN_Mount (1).f3d, KlickyNG_ABSB_mount_3mm_front.stl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]
2022-10-21 add sexbolt mod from hartk modified for kinematic bed
    [Trident_SexBolt_Z_Endstop v1.step, sexbolt_trident_for_kinematic_bed.3mf]
2022-11-13 Organise own mods, stuff to do
    [DIN_Mount (1).f3d, Trident_SexBolt_Z_Endstop v1.step, [a]_tensioner_left_pinned.stl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]
2022-11-17 start modifiying pins for printer motors
    [printer.cfg]
2022-12-04 Octopus configuration start
    - Control octopus via usb,
    - Configured motors pins
    - Configured Y and Z endstop
    [printer.cfg]
2022-12-08 add a bit more configurations
    [printer.cfg]
2022-12-11 Make it work with 2209s, X/Y/Z set Need to dock klicky next
    [mainsail.cfg, printer.cfg, timelapse.cfg]
2022-12-15 Configuration (klicky, bed mesh, temp sensors and nevermore)
    add pid tuning
    add nevermore fan config and temperature sensors for motor and frame
    [klicky-bed-mesh-calibrate.cfg, klicky-macros.cfg, klicky-probe.cfg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]
2022-12-22 Add Front handles from v2.2 Add Rsu brackets (higher for clearance over wires) Add Trident Sexbolt,
    [BottomFrontPanel_extraSized.3mf, Front Panel - Handle Frame.3mf, Front Panel - RHS Latch.3mf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]
